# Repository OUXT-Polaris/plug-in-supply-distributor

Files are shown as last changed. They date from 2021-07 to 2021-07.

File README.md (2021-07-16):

# plug-in-supply-distributor

## Overview

This is one of the boards under development by OUXT for the RobotX competition. It is part of the power supply system for the controller, and has connector interlocking, simple reverse voltage protection, fuse monitoring and external input functions.

KiCAD ( https://www.kicad.org/ ) is used for circuit design and PCB layout.

## CAD

### Version

KiCAD 5.1.7

### Parts Library

The symbol libraries and footprint libraries used in this schematic and PCB layout are basically KiCAD standard libraries, but some of them are in the following repositories.

https://github.com/alnicomag/kicad-custom-lib

## PCB rendering images

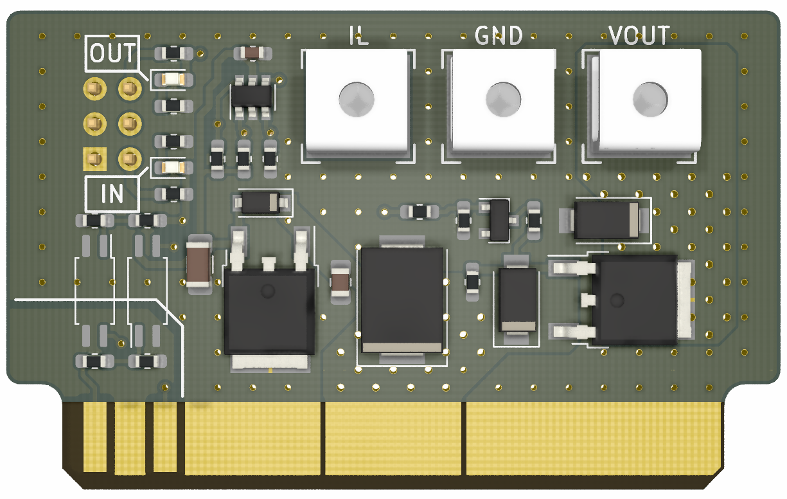
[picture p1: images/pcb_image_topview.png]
Top View

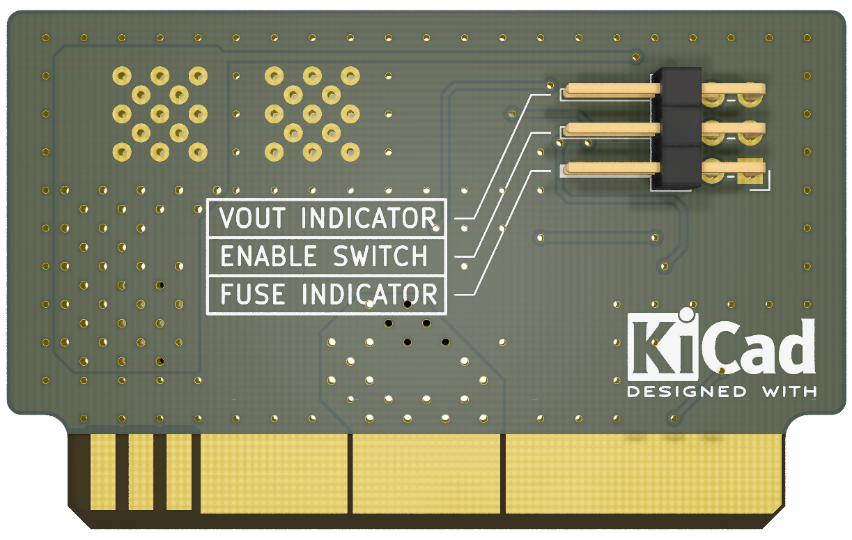
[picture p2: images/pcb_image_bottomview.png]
Bottom View


## Schematics

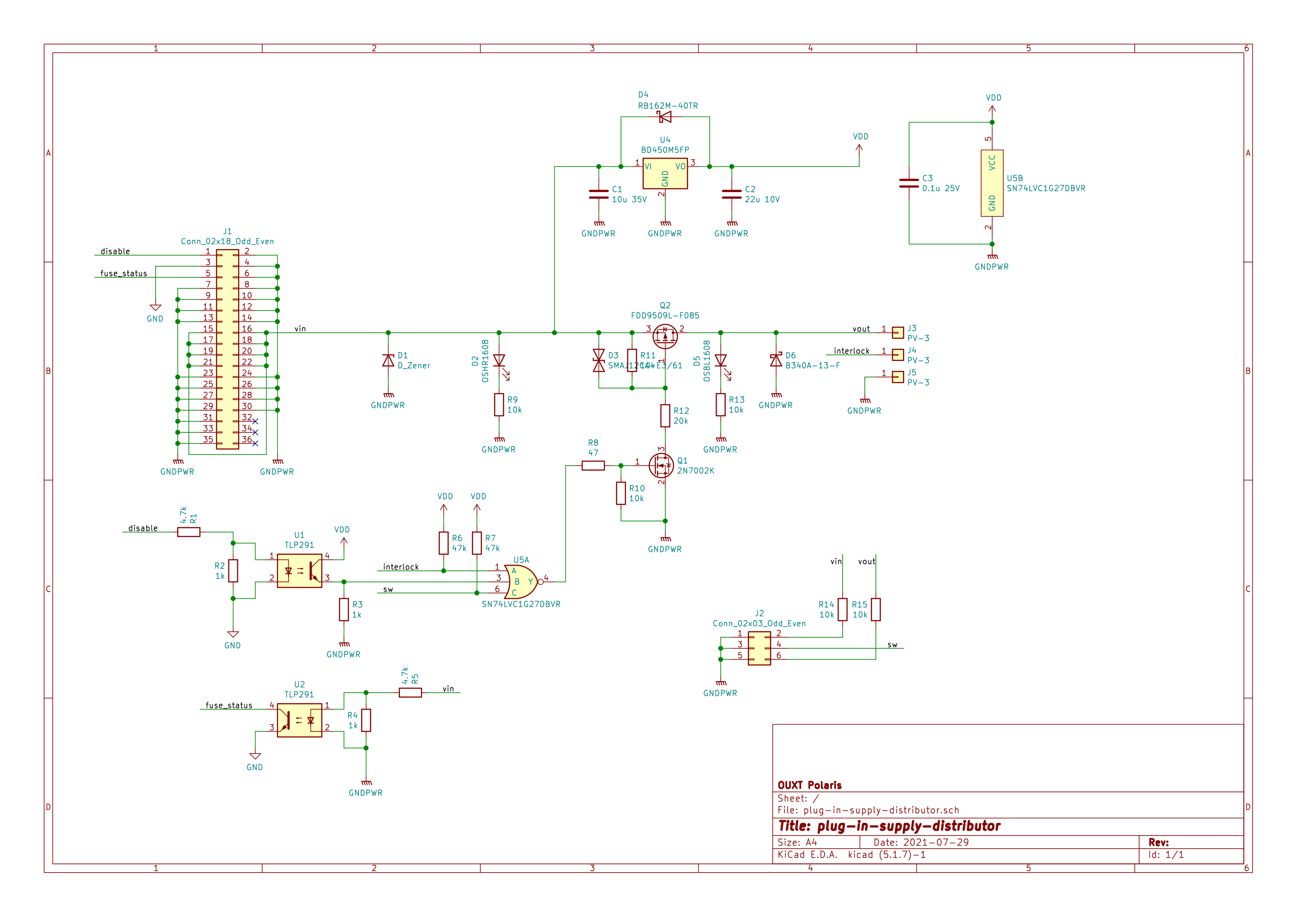
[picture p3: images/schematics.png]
Schematics


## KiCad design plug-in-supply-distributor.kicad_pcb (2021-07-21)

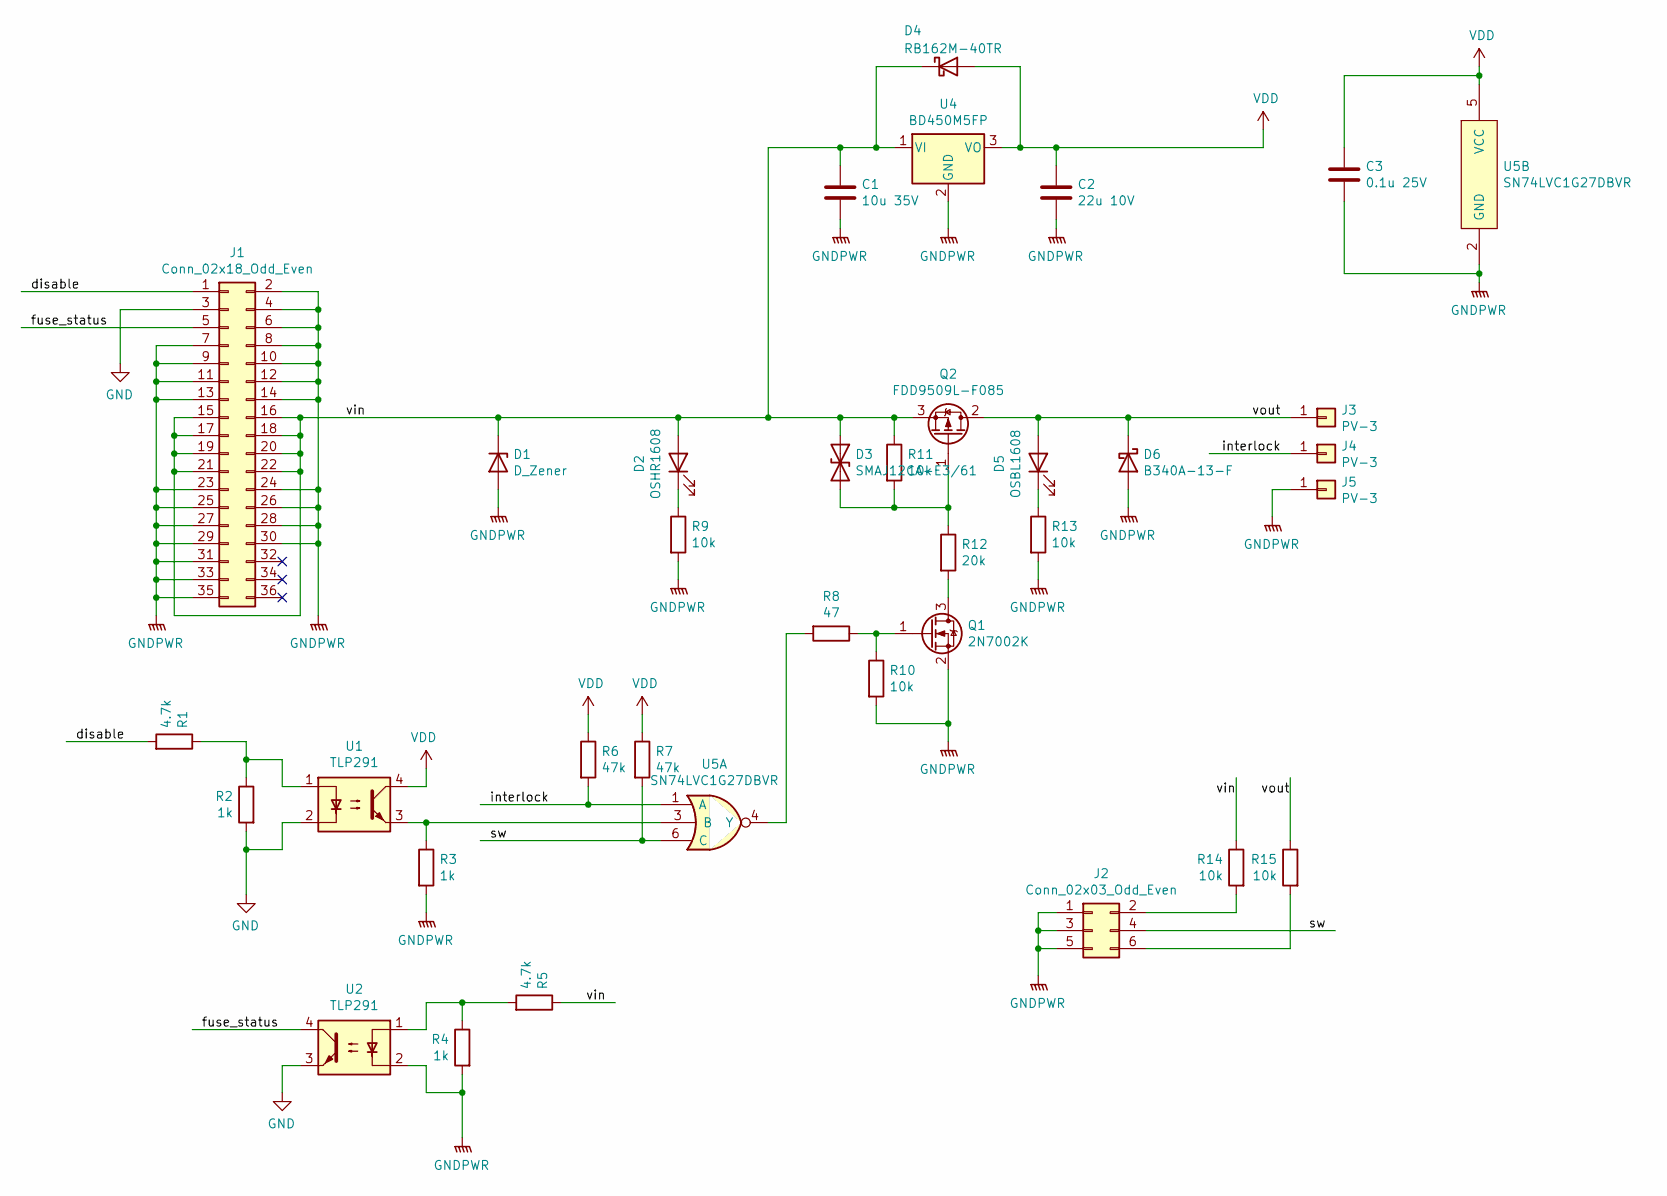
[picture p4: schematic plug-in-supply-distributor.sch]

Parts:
C1: 10u 35V; C_0805_2012Metric_Pad1.18x1.45mm_HandSolder
C2: 22u 10V; C_1206_3216Metric_Pad1.42x1.75mm_HandSolder
C3: 0.1u 25V; C_0603_1608Metric_Pad1.08x0.95mm_HandSolder
D1: D_Zener; D_SMC
D2: OSHR1608; LED_0603_1608Metric_Pad1.05x0.95mm_HandSolder
D3: SMAJ12CA-E3/61; D_SMA
D4: RB162M-40TR; D_SOD-123
D5: OSBL1608; LED_0603_1608Metric_Pad1.05x0.95mm_HandSolder
D6: B340A-13-F; D_SMA
J1: Conn_02x18_Odd_Even; TEConnectivity_2-5530843-7_card-edge
J2: Conn_02x03_Odd_Even; PinHeader_2x03_P2.54mm_Horizontal
J3, J5: PV-3; PV-3_via
J4: PV-3
Q1: 2N7002K; SOT-23
Q2: FDD9509L-F085; TO-252-2
R1, R5: 4.7k; R_0603_1608Metric_Pad1.05x0.95mm_HandSolder
R2, R3, R4: 1k; R_0603_1608Metric_Pad1.05x0.95mm_HandSolder
R6, R7: 47k; R_0603_1608Metric_Pad1.05x0.95mm_HandSolder
R8: 47; R_0603_1608Metric_Pad1.05x0.95mm_HandSolder
R9, R10, R11, R13, R14, R15: 10k; R_0603_1608Metric_Pad1.05x0.95mm_HandSolder
R12: 20k; R_0603_1608Metric_Pad1.05x0.95mm_HandSolder
U1, U2: TLP291; SOIC-4_4.55x2.6mm_P1.27mm
U4: BD450M5FP; TO-252-2
U5: SN74LVC1G27DBVR; SOT-23-6

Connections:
/disable: J1.1, R1.2
/fuse_status: J1.5, U2.4
/interlock: J4.1, R6.2, U5.1 (A)
/sw: J2.4, R7.2, U5.6 (C)
/vin: C1.1, D1.1 (K), D2.2 (A), D3.1 (A1), D4.1 (K), J1.15, J1.16, J1.17, J1.18, J1.19, J1.20, J1.21, J1.22, Q2.3 (S), R5.1, R11.1, R14.1, U4.1 (VI)
/vout: D5.2 (A), D6.1 (K), J3.1, Q2.2 (D), R15.1
GND: J1.3, R2.2, U1.2, U2.3
GNDPWR: C1.2, C2.2, C3.2, D1.2 (A), D6.2 (A), J1.2, J1.4, J1.6, J1.7, J1.8, J1.9, J1.10, J1.11, J1.12, J1.13, J1.14, J1.23, J1.24, J1.25, J1.26, J1.27, J1.28, J1.29, J1.30, J1.31, J1.33, J1.35, J2.1, J2.3, J2.5, J5.1, Q1.2 (S), R3.2, R4.2, R9.2, R10.2, R13.2, U2.2, U4.2 (GND), U5.2 (GND)
unnamed: D2.1 (K), R9.1
unnamed: D3.2 (A2), Q2.1 (G), R11.2, R12.1
unnamed: D5.1 (K), R13.1
unnamed: J2.2, R14.2
unnamed: J2.6, R15.2
unnamed: Q1.1 (G), R8.1, R10.1
unnamed: Q1.3 (D), R12.2
unnamed: R1.1, R2.1, U1.1
unnamed: R3.1, U1.3, U5.3 (B)
unnamed: R4.1, R5.2, U2.1
unnamed: R8.2, U5.4 (Y)
VDD: C2.1, C3.1, D4.2 (A), R6.1, R7.1, U1.4, U4.3 (VO), U5.5 (VCC)

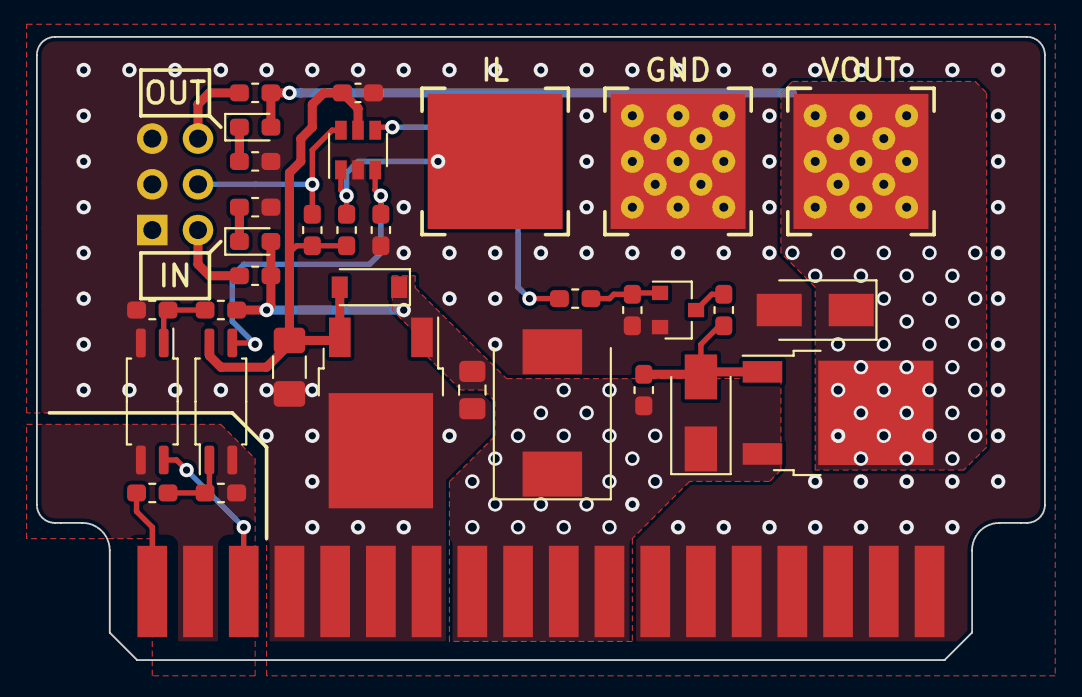
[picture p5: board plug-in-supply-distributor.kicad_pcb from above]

Board: 2 copper layers, 56.0 x 34.6 mm, 35 parts (1 on the bottom side), 20 nets.

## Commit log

2021-06-17 Add kicad files
    [plug-in-supply-distributor.kicad_pcb, plug-in-supply-distributor.sch]
2021-06-17 Add pcb images
2021-06-22 Update pcb layout
    [plug-in-supply-distributor.kicad_pcb]
2021-06-23 Update schematics and pcb layout
    [plug-in-supply-distributor.kicad_pcb, plug-in-supply-distributor.sch]
2021-07-16 Update kicad files
    [plug-in-supply-distributor.kicad_pcb, plug-in-supply-distributor.sch]
2021-07-29 Update schematics
    [plug-in-supply-distributor.sch]
